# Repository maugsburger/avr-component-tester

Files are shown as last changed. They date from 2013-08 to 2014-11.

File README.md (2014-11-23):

avr-component-tester
====================

Board zu http://www.mikrocontroller.net/articles/AVR_Transistortester

* Schaltplan: https://raw.github.com/maugsburger/avr-component-tester/master/tester_sheet1.png
* Platinenvorderseite: https://raw.github.com/maugsburger/avr-component-tester/master/tester_top.png
* Platinenrückseite: https://raw.github.com/maugsburger/avr-component-tester/master/tester_bot.png
* Bauteilliste: https://raw.github.com/maugsburger/avr-component-tester/master/bom.txt

## Features

* Zweiter Spannungsregler für unsaubere Verbraucher
    * DC/DC-Wandler für Zenerdiodentest bis 30V
    * PWM-geregelte LCD-Hintergrundbeleuchtung

* Passt in Strapubox 6000

## Lizenz
<br />This work is licensed under a <a rel="license" href="http://creativecommons.org/licenses/by-sa/4.0/">Creative Commons Attribution-ShareAlike 4.0 International License</a>.

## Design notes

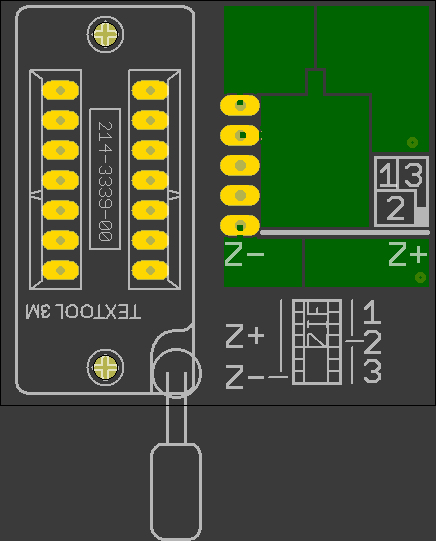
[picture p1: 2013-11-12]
smd-adapter-zif_top.png

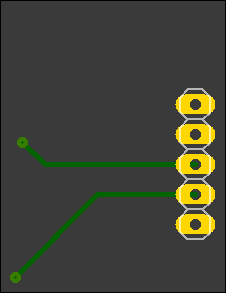
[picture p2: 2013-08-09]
smd-adapter_bot.png

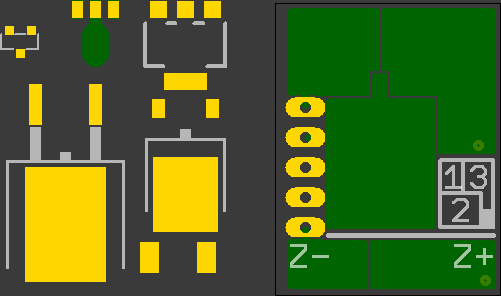
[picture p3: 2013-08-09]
smd-adapter_top.png

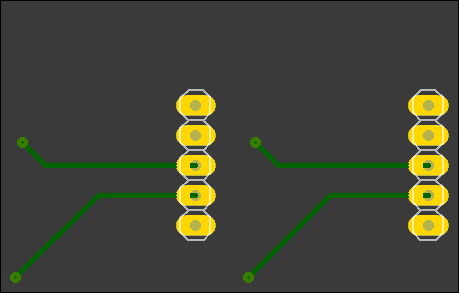
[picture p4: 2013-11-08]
smd-adapter-dual_bot.png

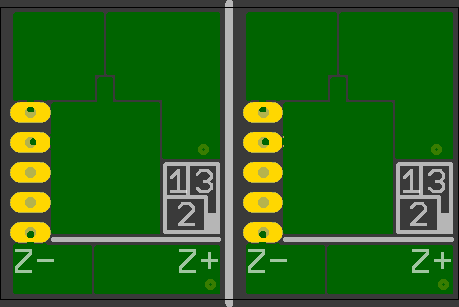
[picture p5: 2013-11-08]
smd-adapter-dual_top.png

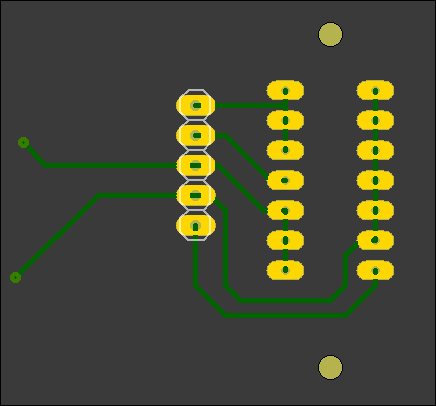
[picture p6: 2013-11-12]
smd-adapter-zif_bot.png

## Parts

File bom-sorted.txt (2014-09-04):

Stückliste exportiert aus /home/mo/projects/eagle/projects/component tester/tester.sch am 9/4/14 9:58 AM

Qty Value          Device                  Package       Parts                        Description                                                  TOLERANCE
1   NA 05W K       NA                      NA            K1                           RELAY                                                                 
1   BAV 103        DIODE-SOD80C            SOD80C        D1                           DIODE                                                                 
1   AB9V           AB9V                    AB9V          G1                           9-V BATTERY CLIP                                                      
1   BC807-40SMD    BC807-40SMD             SOT23-BEC     Q3                           PNP Transistror                                                       
3   BC847CSMD      BC847CSMD               SOT23         Q1, Q2, Q5                   NPN Transistor                                                        
1   BCR421U        BCR421UHAND             SC74_INFINEON U5                           Constant current source: 10mA (without external resistor).            
2   22p            C-EUC0805               C0805         C11, C12                     CAPACITOR, European symbol                                            
1   1n             C-EUC0805               C0805         C1                           CAPACITOR, European symbol                                            
2   10n            C-EUC0805               C0805         C2, C16                      CAPACITOR, European symbol                                            
4   100n           C-EUC0805               C0805         C3, C4, C9, C10              CAPACITOR, European symbol                                            
5   1u             C-EUC0805               C0805         C6, C7, C8, C13, C14         CAPACITOR, European symbol                                            
2   47u            CPOL-EU153CLV-0505      153CLV-0505   C5, C15                      POLARIZED CAPACITOR, European symbol                                  
1   DTS-6          DTS-6                   DTS-6         S1                                                                                                 
1   EA-DOG-M162    EA-DOG-M_LCD            EA_DOGM       DIS1                                                                                               
1   TEST2          FE02-1                  FE02-1        JP7                          FEMALE HEADER                                                         
1   TESTZENER      FE04-1                  FE04-1        JP3                          FEMALE HEADER                                                         
1   TEST           FE05-1                  FE05-1        JP2                          FEMALE HEADER                                                         
1   IRLML6402      IRLML6402               MICRO3        Q6                           HEXFET P-Channel Power MOSFET                                         
1   POWER          LED5MMEXT               LED5MM        LED1                         LED                                                                   
1   10k lin        TRIM_EU-CA9V            CA9V          P2                           POTENTIOMETER                                                         
1   LT1004CZ-2.5   LM329DZ                 TO92          U1                           National Semiconductor LM329                                          
1   LM339D         LM339D                  SO14          U4                           Low Power Low Offset Voltage Quad Comparators                         
2   MCP1702-5002   MCP1702-5002            TO92-LOWDROP  U2, U3                                                                                             
1   ATmega8/88/168 MEGA8-PU                DIL28-3       IC1                                                                                                
1   8,000 MHz      CRYSTALHC49S            HC49/S        Q4                           CRYSTAL                                                               
1   ISP            ML6                     ML6           JP1                          HARTING                                                               
1   NEB21R         NEB21R                  NEB21R        X1                           Netzgeräte-Einbaukupplung abgewinkelte Ausführung mit Öffner          
1   5V/+-15V       NMA                     NMA           DC1                          DC-DC CONVERTER                                                       
1   TESTEXT        PINHD-2X5               2X05          JP4                          PIN HEADER                                                            
1   33k            R-EU_R0805              R0805         R10                          RESISTOR, European symbol                                             
6   10k            R-EU_R0805              R0805         R11, R13, R17, R19, R21, R23 RESISTOR, European symbol                                             
1   4k7            R-EU_R0805              R0805         R15                          RESISTOR, European symbol                                             
1   2k2            R-EU_R0805              R0805         R16                          RESISTOR, European symbol                                             
1   12k            R-EU_R0805              R0805         R22                          RESISTOR, European symbol                                             
3   3k3            R-EU_R0805              R0805         R7, R12, R18                 RESISTOR, European symbol                                             
2   27k            R-EU_R0805              R0805         R8, R14                      RESISTOR, European symbol                                             
2   100k           R-EU_R0805              R0805         R9, R20                      RESISTOR, European symbol                                             
1   180k           R-EU_R0805              R0805         R24                          RESISTOR, European symbol                                    0.1%     
3   680            R-EU_R0805              R0805         R1, R3, R5                   RESISTOR, European symbol                                    0.1%     
1   20k            R-EU_R0805              R0805         R25                          RESISTOR, European symbol                                    0.1%     
3   470k           R-EU_R0805              R0805         R2, R4, R6                   RESISTOR, European symbol                                    0.1%     
1   SB130          SCHOTTKY-DIODE_RAD3-5-A DIODE-3-5A-V  D2                           Schottky Diode                                                        
1   33u            SM-NE29BIGGERPAD        SM-NE29-B     L1                           INDUCTOR                                                              
1   SP6000C-180    SP6000C-180             SP6000C-180   M1                           Gehäuse Strapubox Typ 6000                                            
1   250            TRIM_EU-CA6H            CA6H          P1                           POTENTIOMETER

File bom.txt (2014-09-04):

Stückliste exportiert aus /home/mo/projects/eagle/projects/component tester/tester.sch am 9/3/14 8:42 PM

Part Value          Device                  Package       Description                                                  
C1   1n             C-EUC0805               C0805         CAPACITOR, European symbol                                   
C2   10n            C-EUC0805               C0805         CAPACITOR, European symbol                                   
C3   100n           C-EUC0805               C0805         CAPACITOR, European symbol                                   
C4   100n           C-EUC0805               C0805         CAPACITOR, European symbol                                   
C5   47u            CPOL-EU153CLV-0505      153CLV-0505   POLARIZED CAPACITOR, European symbol                         
C6   1u             C-EUC0805               C0805         CAPACITOR, European symbol                                   
C7   1u             C-EUC0805               C0805         CAPACITOR, European symbol                                   
C8   1u             C-EUC0805               C0805         CAPACITOR, European symbol                                   
C9   100n           C-EUC0805               C0805         CAPACITOR, European symbol                                   
C10  100n           C-EUC0805               C0805         CAPACITOR, European symbol                                   
C11  22p            C-EUC0805               C0805         CAPACITOR, European symbol                                   
C12  22p            C-EUC0805               C0805         CAPACITOR, European symbol                                   
C13  1u             C-EUC0805               C0805         CAPACITOR, European symbol                                   
C14  1u             C-EUC0805               C0805         CAPACITOR, European symbol                                   
C15  47u            CPOL-EU153CLV-0505      153CLV-0505   POLARIZED CAPACITOR, European symbol                         
C16  10n            C-EUC0805               C0805         CAPACITOR, European symbol                                   
D1   BAV 103        DIODE-SOD80C            SOD80C        DIODE                                                        
D2   SB130          SCHOTTKY-DIODE_RAD3-5-A DIODE-3-5A-V  Schottky Diode                                               
DC1  5V/+-15V       NMA                     NMA           DC-DC CONVERTER                                              
DIS1 EA-DOG-M162    EA-DOG-M_LCD            EA_DOGM                                                                    
G1   AB9V           AB9V                    AB9V          9-V BATTERY CLIP                                             
IC1  ATmega8/88/168 MEGA8-PU                DIL28-3                                                                    
JP1  ISP            ML6                     ML6           HARTING                                                      
JP2  TEST           FE05-1                  FE05-1        FEMALE HEADER                                                
JP3  TESTZENER      FE04-1                  FE04-1        FEMALE HEADER                                                
JP4  TESTEXT        PINHD-2X5               2X05          PIN HEADER                                                   
JP7  TEST2          FE02-1                  FE02-1        FEMALE HEADER                                                
K1   NA 05W K       NA                      NA            RELAY                                                        
L1   33u            SM-NE29BIGGERPAD        SM-NE29-B     INDUCTOR                                                     
LED1 POWER          LED5MMEXT               LED5MM        LED                                                          
M1   SP6000C-180    SP6000C-180             SP6000C-180   Gehäuse Strapubox Typ 6000                                   
P1   250            TRIM_EU-CA6H            CA6H          POTENTIOMETER                                                
P2   10k lin        TRIM_EU-CA9V            CA9V          POTENTIOMETER                                                
Q1   BC847CSMD      BC847CSMD               SOT23         NPN Transistor                                               
Q2   BC847CSMD      BC847CSMD               SOT23         NPN Transistor                                               
Q3   BC807-40SMD    BC807-40SMD             SOT23-BEC     PNP Transistror                                              
Q4   8,000 MHz      CRYSTALHC49S            HC49/S        CRYSTAL                                                      
Q5   BC847CSMD      BC847CSMD               SOT23         NPN Transistor                                               
Q6   IRLML6402      IRLML6402               MICRO3        HEXFET P-Channel Power MOSFET                                
R1   680            R-EU_R0805              R0805         RESISTOR, European symbol                                    
R2   470k           R-EU_R0805              R0805         RESISTOR, European symbol                                    
R3   680            R-EU_R0805              R0805         RESISTOR, European symbol                                    
R4   470k           R-EU_R0805              R0805         RESISTOR, European symbol                                    
R5   680            R-EU_R0805              R0805         RESISTOR, European symbol                                    
R6   470k           R-EU_R0805              R0805         RESISTOR, European symbol                                    
R7   3k3            R-EU_R0805              R0805         RESISTOR, European symbol                                    
R8   27k            R-EU_R0805              R0805         RESISTOR, European symbol                                    
R9   100k           R-EU_R0805              R0805         RESISTOR, European symbol                                    
R10  33k            R-EU_R0805              R0805         RESISTOR, European symbol                                    
R11  10k            R-EU_R0805              R0805         RESISTOR, European symbol                                    
R12  3k3            R-EU_R0805              R0805         RESISTOR, European symbol                                    
R13  10k            R-EU_R0805              R0805         RESISTOR, European symbol                                    
R14  27k            R-EU_R0805              R0805         RESISTOR, European symbol                                    
R15  4k7            R-EU_R0805              R0805         RESISTOR, European symbol                                    
R16  2k2            R-EU_R0805              R0805         RESISTOR, European symbol                                    
R17  10k            R-EU_R0805              R0805         RESISTOR, European symbol                                    
R18  3k3            R-EU_R0805              R0805         RESISTOR, European symbol                                    
R19  10k            R-EU_R0805              R0805         RESISTOR, European symbol                                    
R20  100k           R-EU_R0805              R0805         RESISTOR, European symbol                                    
R21  10k            R-EU_R0805              R0805         RESISTOR, European symbol                                    
R22  12k            R-EU_R0805              R0805         RESISTOR, European symbol                                    
R23  10k            R-EU_R0805              R0805         RESISTOR, European symbol                                    
R24  180k           R-EU_R0805              R0805         RESISTOR, European symbol                                    
R25  20k            R-EU_R0805              R0805         RESISTOR, European symbol                                    
S1   DTS-6          DTS-6                   DTS-6                                                                      
U1   LT1004CZ-2.5   LM329DZ                 TO92          National Semiconductor LM329                                 
U2   MCP1702-5002   MCP1702-5002            TO92-LOWDROP                                                               
U3   MCP1702-5002   MCP1702-5002            TO92-LOWDROP                                                               
U4   LM339D         LM339D                  SO14          Low Power Low Offset Voltage Quad Comparators                
U5   BCR421U        BCR421UHAND             SC74_INFINEON Constant current source: 10mA (without external resistor).   
X1   NEB21R         NEB21R                  NEB21R        Netzgeräte-Einbaukupplung abgewinkelte Ausführung mit Öffner

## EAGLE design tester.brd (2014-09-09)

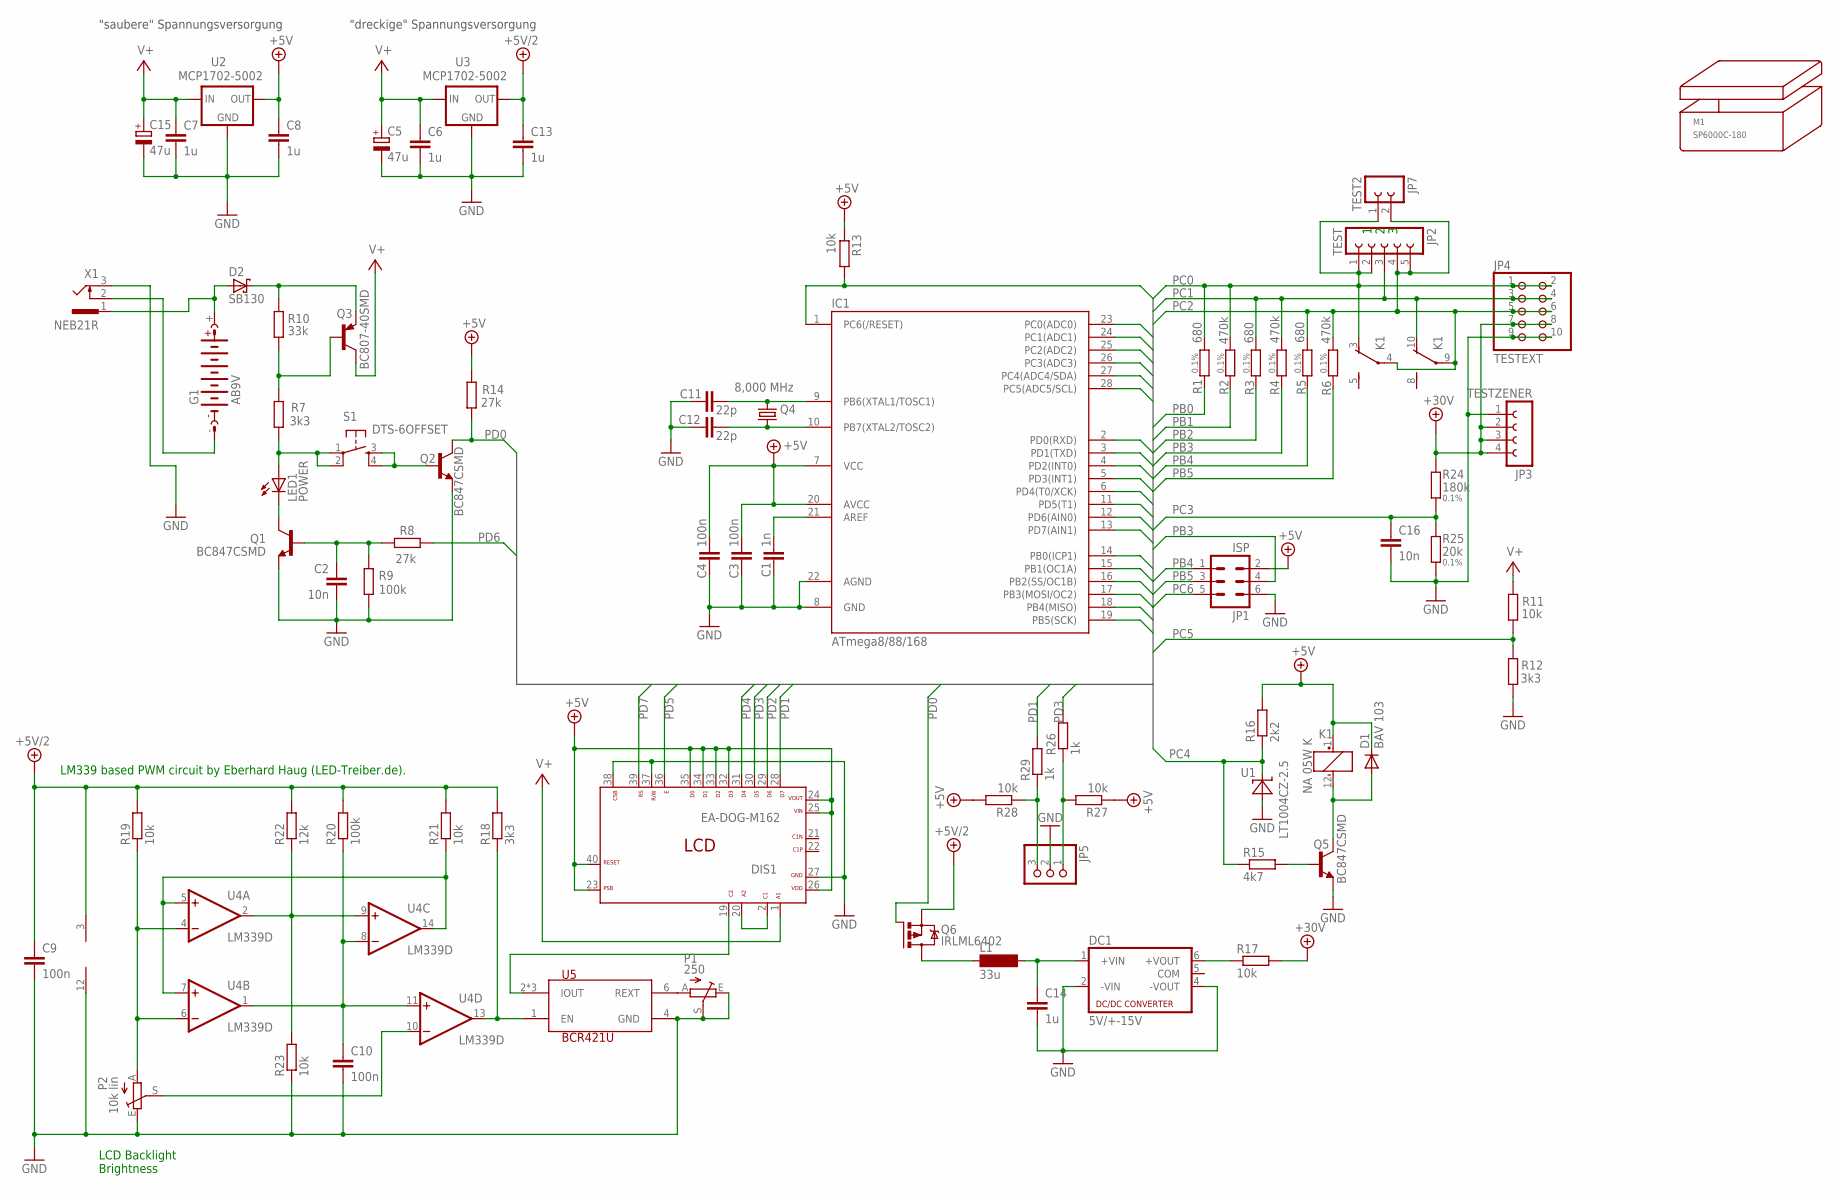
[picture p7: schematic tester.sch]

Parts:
C1: 1n; C0805
C2, C16: 10n; C0805
C3, C4, C9, C10: 100n; C0805
C5, C15: 47u; 153CLV-0505
C6, C7, C8, C13, C14: 1u; C0805
C11, C12: 22p; C0805
D1: BAV 103; SOD80C
D2: SB130; DIODE-3-5A-V
DC1: 5V/+-15V; NMA
DIS1: EA-DOG-M162; EA_DOGM
G1: AB9V
IC1: ATmega8/88/168; DIL28-3
JP1: ISP; ML6
JP2: TEST; FE05-1
JP3: TESTZENER; FE04-1
JP4: TESTEXT; 2X05
JP5: PINHD-1X3; 1X03
JP7: TEST2; FE02-1
K1: NA 05W K; NA
L1: 33u; SM-NE29-B
LED1: POWER; LED5MM
M1: SP6000C-180
P1: 250; CA6H
P2: 10k lin; CA9V
Q1, Q2, Q5: BC847CSMD; SOT23
Q3: BC807-40SMD; SOT23-BEC
Q4: 8,000 MHz; HC49/S
Q6: IRLML6402; MICRO3
R1, R3, R5: 680; R0805; TOLERANCE 0.1%
R2, R4, R6: 470k; R0805; TOLERANCE 0.1%
R7, R12, R18: 3k3; R0805
R8, R14: 27k; R0805
R9, R20: 100k; R0805
R10: 33k; R0805
R11, R13, R17, R19, R21, R23, R27, R28: 10k; R0805
R15: 4k7; R0805
R16: 2k2; R0805
R22: 12k; R0805
R24: 180k; R0805; TOLERANCE 0.1%
R25: 20k; R0805; TOLERANCE 0.1%
R26, R29: 1k; R0805
S1: DTS-6OFFSET; DTS-6S
U1: LT1004CZ-2.5; TO92
U2, U3: MCP1702-5002; TO92-LOWDROP
U4: LM339D; SO14
U5: BCR421U; SC74_INFINEON
X1: NEB21R

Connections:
+5V: C3.2, C4.1, C8.1, D1.C, DIS1.23, DIS1.24, DIS1.25, DIS1.26, DIS1.32, DIS1.33, DIS1.34, DIS1.35, DIS1.40, IC1.7 (VCC), IC1.20 (AVCC), JP1.2, K1.1 (+), R13.1, R14.2, R16.2, R27.1, R28.2, U2.OUT
+5V/2: C9.1, C13.1, Q6.2 (S), R18.2, R19.2, R20.2, R21.2, R22.2, U3.OUT, U4.3 (V+)
+30V: JP3.2, JP3.3, JP3.4, JP4.7, JP4.8, R17.2, R24.2
AREF: C1.2, IC1.21 (AREF)
GND: C1.1, C2.2, C3.1, C4.2, C5.-, C6.2, C7.2, C8.2, C9.2, C10.2, C11.1, C12.1, C13.2, C14.2, C15.-, C16.2, DC1.2 (-VIN), DC1.4 (-VOUT), DIS1.27, DIS1.37, DIS1.38, IC1.8 (GND), IC1.22 (AGND), JP1.6, JP3.1, JP4.9, JP4.10, JP5.2, P1.E, P1.S, P2.E, Q1.2 (E), Q2.2 (E), Q5.2 (E), R9.1, R12.1, R23.1, R25.1, U1.1 (A), U2.GND, U3.GND, U4.12 (GND), U5.4 (GND), X1.3
unnamed: P1.A, U5.6 (REXT)
unnamed: DIS1.2, DIS1.20
unnamed: Q2.1 (B), S1.3, S1.4
unnamed: R22.1, R23.2, U4.2 (OUT), U4.9 (+IN)
unnamed: G1.-, X1.2
unnamed: C10.1, R20.1, U4.1 (OUT), U4.8 (-IN), U4.11 (+IN)
unnamed: R21.1, U4.5 (+IN), U4.7 (+IN), U4.14 (OUT)
unnamed: LED1.K (C), Q1.3 (C)
unnamed: D2.C, Q3.E, R10.1
unnamed: DIS1.19, U5.2 (IOUT), U5.3 (IOUT), U5.5 (IOUT)
unnamed: C11.2, IC1.9 (PB6(XTAL1/TOSC1)), Q4.2
unnamed: C12.2, IC1.10 (PB7(XTAL2/TOSC2)), Q4.1
unnamed: JP5.3, R28.1, R29.1
unnamed: P2.A, R19.1, U4.4 (-IN), U4.6 (-IN)
unnamed: P2.S, U4.10 (-IN)
unnamed: R18.1, U4.13 (OUT), U5.1 (EN)
unnamed: D1.A, K1.12 (-), Q5.3 (C)
unnamed: JP5.1, R26.1, R27.2
unnamed: LED1.A, R7.1, S1.1, S1.2
unnamed: Q5.1 (B), R15.2
unnamed: D2.A, G1.+, X1.1
unnamed: L1.1, Q6.3 (D)
unnamed: C14.1, DC1.1 (+VIN), L1.2
unnamed: DC1.6 (+VOUT), R17.1
unnamed: Q3.B, R7.2, R10.2
unnamed: C2.1, Q1.1 (B), R8.2, R9.2
PB0: IC1.14 (PB0(ICP1)), R1.1
PB1: IC1.15 (PB1(OC1A)), R2.1
PB2: IC1.16 (PB2(SS/OC1B)), R3.1
PB3: IC1.17 (PB3(MOSI/OC2)), JP1.4, R4.1
PB4: IC1.18 (PB4(MISO)), JP1.1, R5.1
PB5: IC1.19 (PB5(SCK)), JP1.3, R6.1
PC0: IC1.23 (PC0(ADC0)), JP2.1, JP2.2, JP4.1, JP4.2, JP7.1, K1.3 (O), R1.2, R2.2
PC1: IC1.24 (PC1(ADC1)), JP2.3, JP4.3, JP4.4, K1.10 (O), R3.2, R4.2
PC2: IC1.25 (PC2(ADC2)), JP2.4, JP2.5, JP4.5, JP4.6, JP7.2, K1.4, K1.9, R5.2, R6.2
PC3: C16.1, IC1.26 (PC3(ADC3)), R24.1, R25.2
PC4: IC1.27 (PC4(ADC4/SDA)), R15.1, R16.1, U1.2 (C)
PC5: IC1.28 (PC5(ADC5/SCL)), R11.2, R12.2
PC6: IC1.1 (PC6(/RESET)), JP1.5, R13.2
PD0: IC1.2 (PD0(RXD)), Q2.3 (C), Q6.1 (G), R14.1
PD1: DIS1.28, IC1.3 (PD1(TXD)), R29.2
PD2: DIS1.29, IC1.4 (PD2(INT0))
PD3: DIS1.30, IC1.5 (PD3(INT1)), R26.2
PD4: DIS1.31, IC1.6 (PD4(T0/XCK))
PD5: DIS1.36, IC1.11 (PD5(T1))
PD6: IC1.12 (PD6(AIN0)), R8.1
PD7: DIS1.39, IC1.13 (PD7(AIN1))
V+: C5.+, C6.1, C7.1, C15.+, DIS1.1, Q3.C, R11.1, U2.IN, U3.IN

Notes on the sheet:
LCD Backlight Brightness
LM339 based PWM circuit by Eberhard Haug (LED-Treiber.de).
"saubere" Spannungsversorgung
"dreckige" Spannungsversorgung

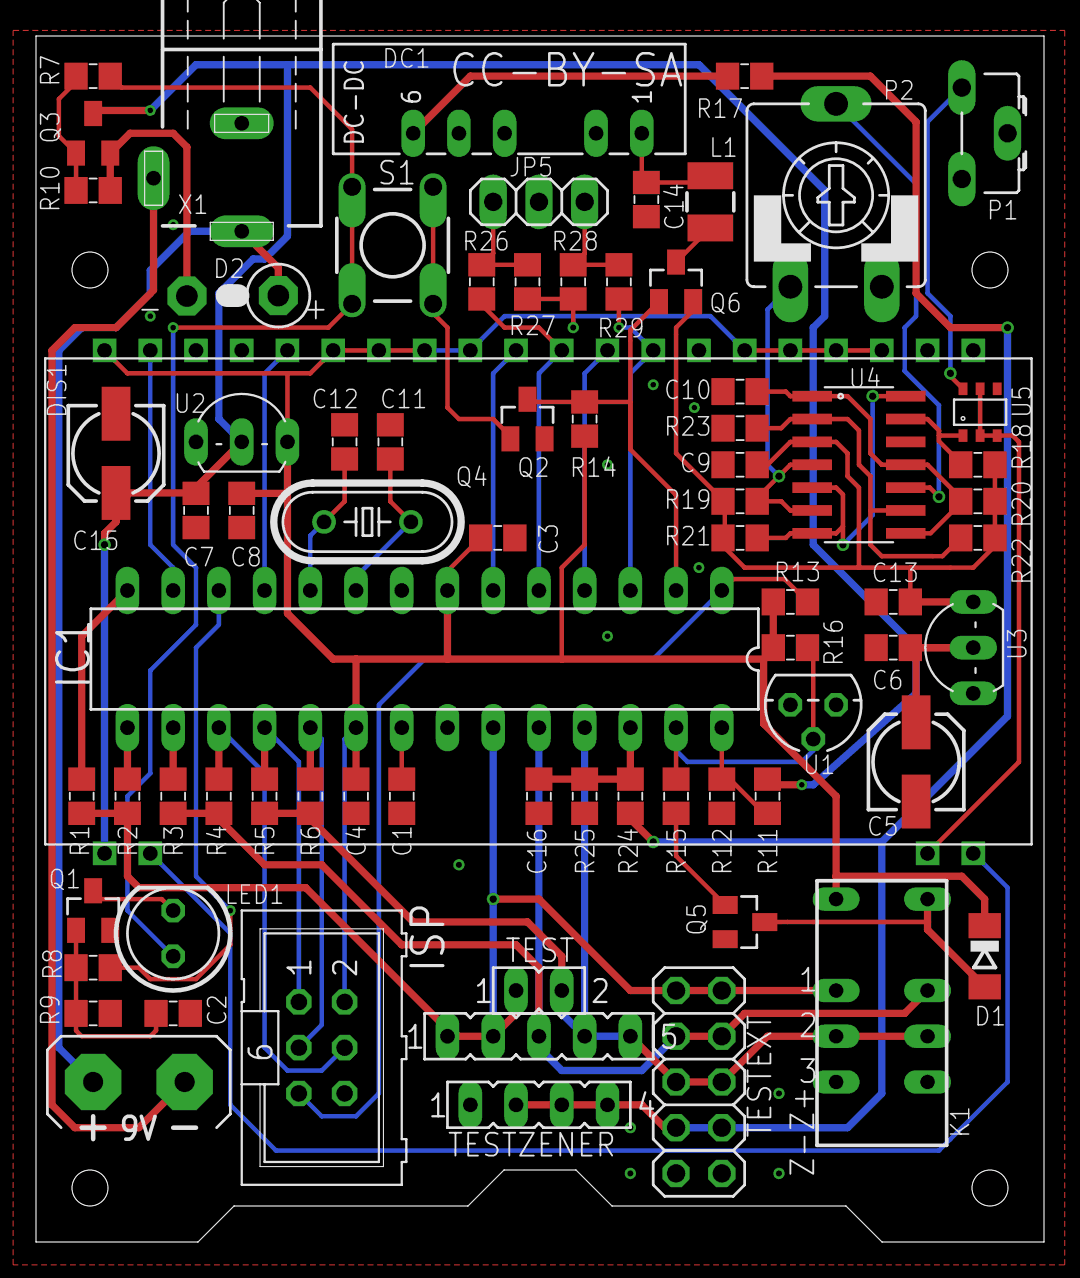
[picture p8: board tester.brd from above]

Board: 2 copper layers, 56.0 x 67.0 mm, 76 parts (0 on the bottom side), 53 nets.

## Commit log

2013-04-18 history replay r0
    [tester.brd, tester.sch]
2013-04-18 history replay r2
    [tester.brd, tester.sch]
2013-04-18 history replay r3
    [tester.brd, tester.sch]
2013-04-18 history replay r4
    [tester.brd, tester.sch]
2013-04-18 history replay r5
    [tester.brd, tester.sch]
2013-04-18 history replay r6
    [tester.brd, tester.sch]
2013-04-18 history replay r7
    [tester.brd, tester.sch]
2013-04-18 added licence info on board
    [tester.brd]
2013-06-07 rearranged top mask
    [tester.brd, tester.sch]
2013-06-07 cleaned up some capacitor values, changed P2 to available pinout type
    [tester.brd, tester.sch]
2013-06-10 switched lcd wiring to streifenraster
    [tester.brd, tester.sch]
2013-06-10 power lcd bg led directly from v+
    [tester.brd, tester.sch]
2013-06-10 rearranged some parts, variant without pwm
    [tester.brd, tester.sch]
2013-06-10 smd for q3
    [tester.brd, tester.sch]
2013-06-13 power lcd bg led in series
    [tester.brd, tester.sch]
2013-06-17 adjusted 1702 filter caps
    [tester.brd, tester.sch]
2013-06-17 should know better how to use npn q5
    [tester.brd, tester.sch]
2013-06-18 changed all r/c to 0805, resized some pads, hopefully made easier to solder
    [tester.brd, tester.sch]
2013-07-19 some change
    [tester.brd, tester.sch]
2013-07-19 switch case back, oshpark dru
    [tester.brd, tester.sch]
2013-07-19 0805 pad size and silk print
    [tester.brd, tester.sch]
2013-07-19 no more c from resistor lib, all rcl now
    [tester.brd, tester.sch]
2013-07-19 more silk screen tuning
    [tester.brd]
2013-07-19 lib fine tuning
    [tester.brd, tester.sch]
2013-07-19 silk screen on pads
    [tester.brd]
2013-07-22 continous part names/numbers
    [tester.brd, tester.sch]
2013-07-22 bill of materials
2013-07-24 local oscillator gnd plane
    [tester.brd]
2013-08-05 fix for reichelt r25 20k .1% n/a => parallel r25 22k and r26 220k
    [tester.brd, tester.sch]
2013-08-05 Revert "fix for reichelt"
    This reverts commit 00bdf40ca26db270fa33158348546dbcbdb5b146.
    Reichelt offers 162K/18K => 1:10-divider
    [tester.brd, tester.sch]
2013-08-08 gerber for dfrobot
    [tester+adapter.GBL, tester+adapter.GBO, tester+adapter.GBP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]
2013-08-09 corrected angles
    [tester.brd, tester.sch]
2013-08-27 remove gerber out
    [tester+adapter.GBL, tester+adapter.GBO, tester+adapter.GBP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]
2013-09-13 remove obsolete files
    [tester+adapter.brd]
2013-10-04 IRLML 6402 for Q6
    [tester.brd, tester.sch]
2013-11-08 combined zif/smd adapter
    [smd-adapter-zif.brd]
2013-11-08 dual smd adapter
    [smd-adapter-dual.brd]
2013-11-08 change q6, s1
    remove q6 option for irfr9024
    tactile switch s1 instead of pin header
    [tester.brd, tester.sch]
2013-11-12 add silk screen for zif pin usage
    [smd-adapter-zif.brd]
2014-09-03 bigger pads for L1
    [tester.brd, tester.sch]
2014-09-03 move ext-header a little bit down
    [tester.brd]
2014-09-03 moved external connector to the left
    [tester.brd]
2014-09-03 move testext silkprint onto pcb
    [tester.brd]
2014-09-04 added bom
2014-09-04 added rotary encoder
    [tester.brd, tester.sch]
2014-09-04 moded resistors below atmel a little bit down
    [tester.brd]
2014-09-04 normal polarity for neb21, gnd is outside
    [tester.brd, tester.sch]
2014-09-09 rotary encoder is PD1 and PD3
    [tester.brd, tester.sch]

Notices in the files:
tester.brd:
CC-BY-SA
